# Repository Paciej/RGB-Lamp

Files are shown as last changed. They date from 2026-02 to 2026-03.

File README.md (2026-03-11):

# Smart RGB LED Lamp — BLE Controlled (ESP32)

A Bluetooth Low Energy (BLE) controlled RGB LED lamp built on the ESP32 microcontroller.
The lamp supports multiple lighting modes, real-time color and brightness control,
and temperature monitoring — all controllable wirelessly via **nRF Connect** app.
A dedicated mobile application is currently under development.

---

## PCB Design (Eagle)

> Schematic and board layout designed in Eagle CAD.
<p align="center">
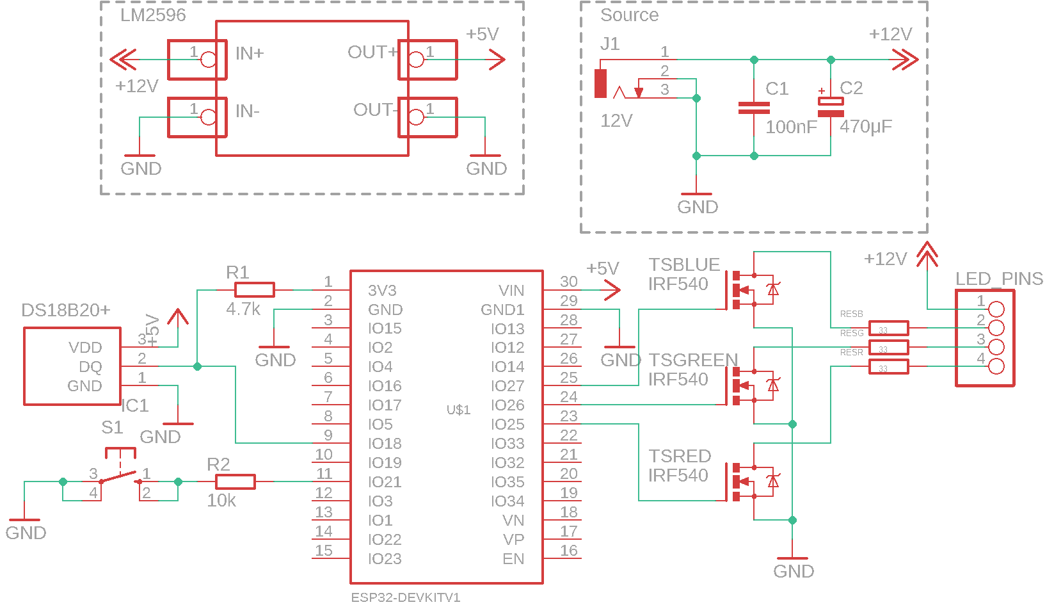
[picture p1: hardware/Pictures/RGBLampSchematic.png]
Eagle Schematic

</p>
<p align="center">
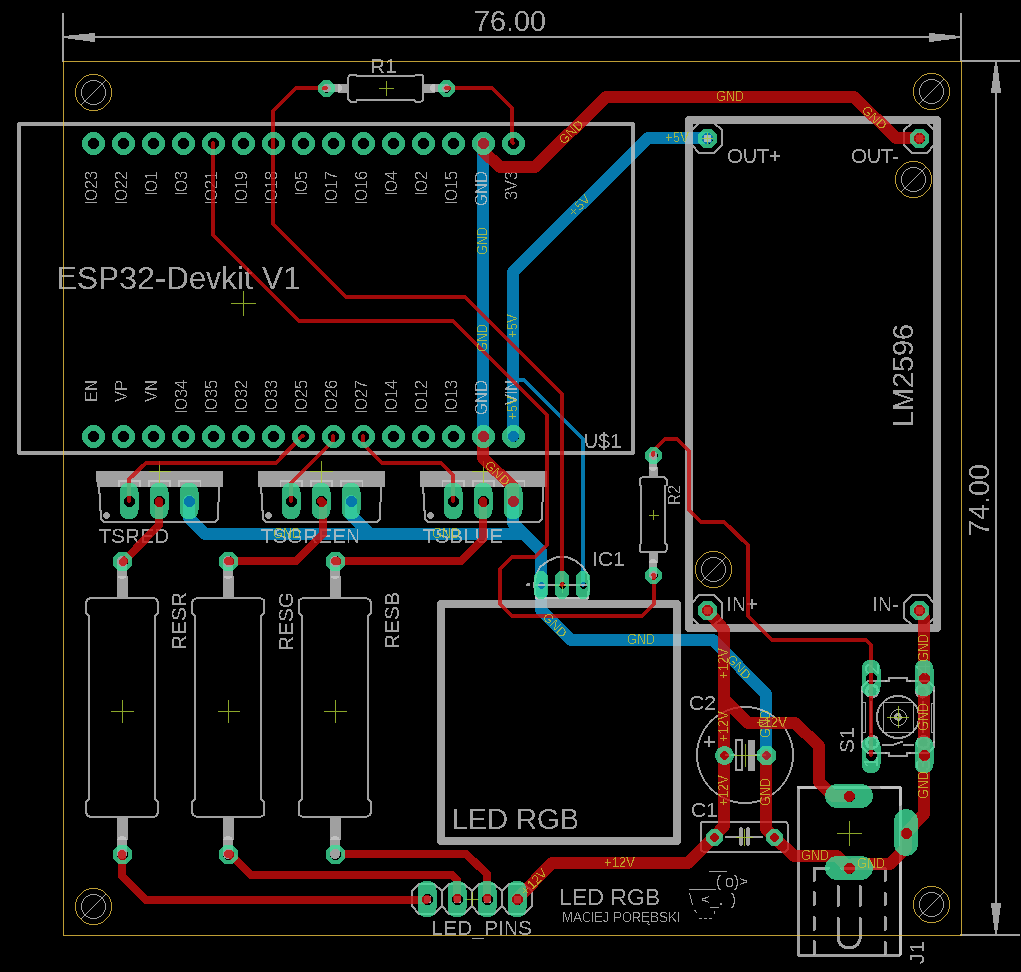
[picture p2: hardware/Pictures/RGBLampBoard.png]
Eagle PCB Layout

</p>
---

## Printed & Assembled PCB

> Physical PCB after printing and soldering.
<p align="center">
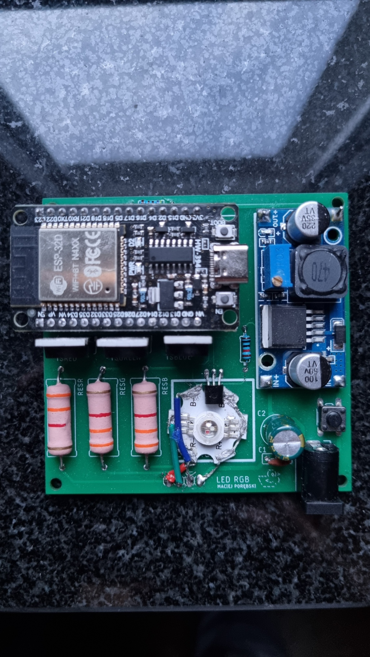
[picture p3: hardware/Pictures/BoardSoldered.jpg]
Soldered PCB
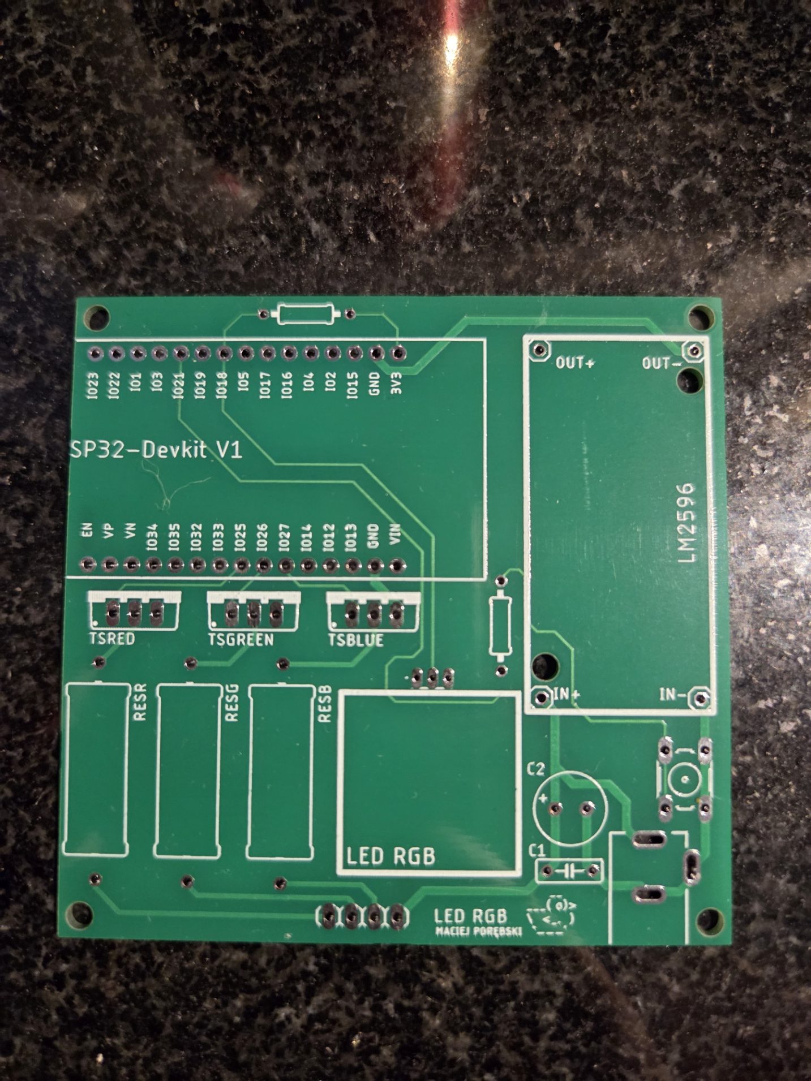
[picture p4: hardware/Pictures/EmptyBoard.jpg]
Printed PCB
 
</p>
---

## Control via nRF Connect

> The lamp is currently controlled using the **nRF Connect** mobile app.
> Temperature readings are exposed as a BLE characteristic and visible directly in the app.
<p align="center">
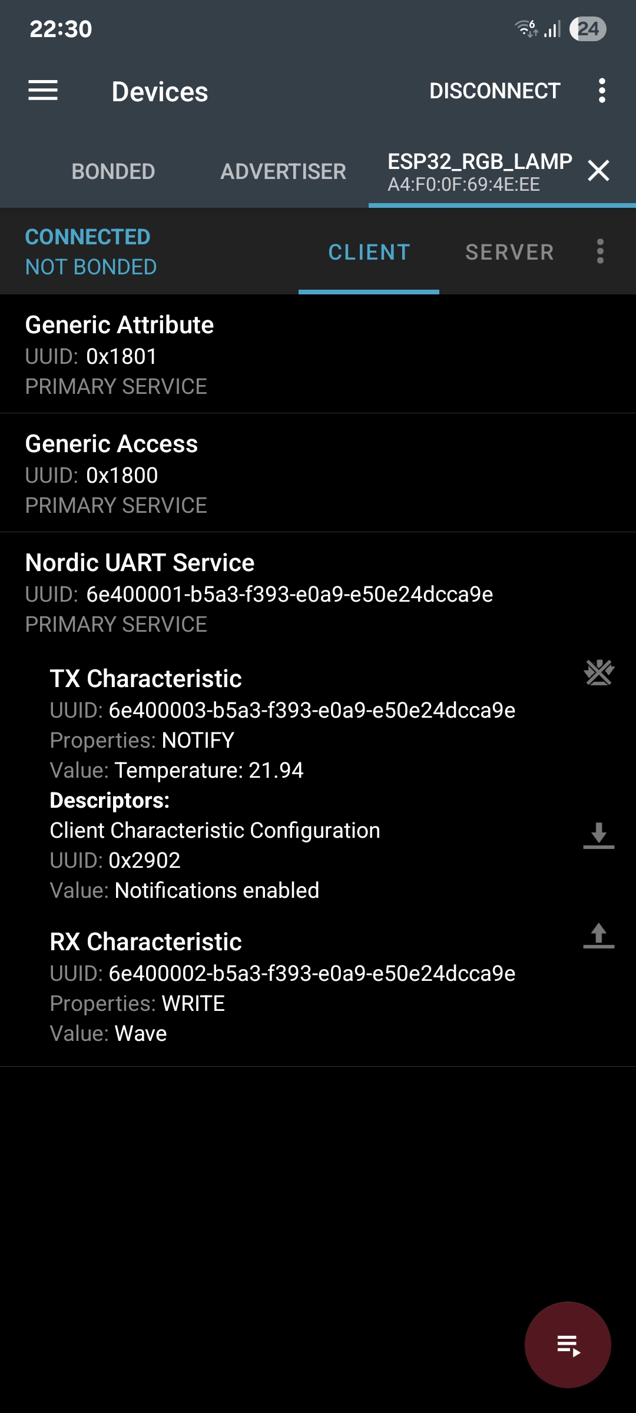
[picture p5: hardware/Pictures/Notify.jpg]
nRF Connect - Temperature Reading

</p>
---

##  Lighting Modes

### Random Color — Physical Button
> Press the physical button to apply a random color using ESP32's hardware RNG.

<p align="center">
  Random Color Button Demo
</p>

---

### Candle Mode
> Simulates a realistic flickering candle effect.

<p align="center">
  Candle Mode Demo
</p>

---

### Pulse Mode
> Smooth brightness breathing effect.

<p align="center">
  Pulse Mode Demo
</p>

---

### Wave Mode
> Seamless smooth transitions across the full RGB spectrum.

<p align="center">
  Wave Mode Demo
</p>

---

##  Features

-  **Full RGB color control** — set any color via BLE (values 0–255 per channel)
-  **Brightness control** via MOSFET PWM (low-side configuration)
-  **Temperature monitoring** — DS18B20 sensor exposed as a BLE characteristic
-  **Random color button** — applies a random color using ESP32's hardware RNG
-  **Lighting modes:**
  - Candle (flicker simulation)
  - Pulse (breathing effect)
  - Wave (smooth RGB transitions)
-  **BLE communication** — controlled via nRF Connect (dedicated app in development)

---

##  Pin Configuration (ESP32 DevKit)

| Pin | Function | Component |
|-----|---|---|
| 23 | Red channel (PWM) | RGB LED — Red |
| 24 | Green channel (PWM) | RGB LED — Green |
| 25 | Blue channel (PWM) | RGB LED — Blue |
| 9 | 1-Wire data | DS18B20 Temperature Sensor |
| 11 | Button input | Random color trigger |

---

##  Hardware Components

| Component | Description |
|---|---|
| **ESP32 DevKit** | Main microcontroller with built-in BLE |
| **RGB LED 3W (Star)** | High-brightness point light source |
| **MOSFET (×3)** | Low-side PWM drivers for each RGB channel |
| **LM2596 Buck Converter Module** | Steps down 12V supply to 3.3V for ESP32 |
| **DS18B20** | Digital 1-Wire temperature sensor |
| **Resistor 33Ω 5W** | Custom current-limiting resistor |
| **Push Button** | Physical control for random color |

>  The repository includes pre-built external libraries for ESP32 DevKit, DS18B20,
> and the custom 33Ω 5W resistor component (Eagle library).

---

##  Libraries

The project uses the following external libraries bundled in the repository:

- `ESP32 BLE Arduino` — BLE GATT server implementation
- `DallasTemperature` + `OneWire` — DS18B20 sensor support
- Custom Eagle component library — 33Ω 5W resistor footprint

---

## Setup

1. Open the project in **Arduino IDE** or **PlatformIO**
2. Select board: `ESP32 Dev Module`
3. Install libraries from the `/libraries` folder (or use the bundled ones)
4. Flash the firmware to your ESP32
5. Open **nRF Connect** on your mobile device
6. Scan for the device and connect
7. Use GATT characteristics to:
   - Write RGB values (3 bytes: R, G, B)
   - Write lighting mode
   - Read temperature

---

##  BLE Control (nRF Connect)

Until the dedicated app is released, the lamp can be fully controlled via **nRF Connect**:

- Write `[R, G, B]` bytes to the color characteristic to set color
- Write a mode byte to switch lighting modes:
  - `Candle` — Candle
  - `Pulse` — Pulse
  - `Wave` — Wave
- Read the temperature characteristic to monitor the LED temperature

---

##  Project Info

- **University:** Silesian University of Technology
- **Faculty:** Faculty of Automatic Control, Electronics and Computer Science
- **Subject:** Microprocessor and embedded systems
- **Author:** Maciej Porębski

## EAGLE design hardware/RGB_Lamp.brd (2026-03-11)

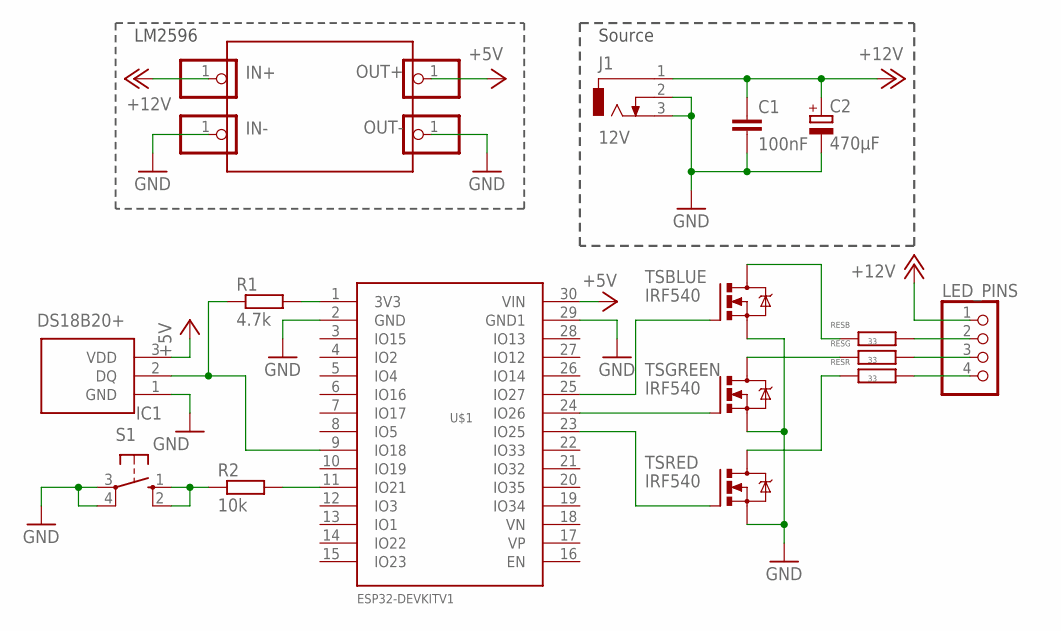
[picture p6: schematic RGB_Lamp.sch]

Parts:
C1: 100nF; C050-025X075
C2: 470μF; E3,5-8
IC1: DS18B20+; DS18B20
IN+: PINHD-1X1; 1X01
IN-: PINHD-1X1; 1X01
J1: 12V; DCJ0303
LED_PINS: PINHD-1X4; 1X04
OUT+: PINHD-1X1; 1X01
OUT-: PINHD-1X1; 1X01
R1: 4.7k; 0207/10
R2: 10k; 0207/10
RESB: 33; 0922/22
RESG: 33; 0922/22
RESR: 33; 0922/22
S1: 10-XX; B3F-10XX
TSBLUE: IRF540; TO220BV
TSGREEN: IRF540; TO220BV
TSRED: IRF540; TO220BV
U$1: ESP32DEVKITV1; ESP32-DEVKITV1

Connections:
+5V: IC1.3 (VDD), OUT+.1, U$1.30 (VIN)
+12V: C1.1, C2.+, IN+.1, J1.1, LED_PINS.1
B: RESR.1, TSRED.D
GND: C1.2, C2.-, IC1.1 (GND), IN-.1, J1.2, J1.3, OUT-.1, S1.3, S1.4 (P1), TSBLUE.S, TSGREEN.S, TSRED.S, U$1.2 (GND), U$1.29 (GND1)
unnamed: R2.1, S1.1 (S), S1.2 (S1)
unnamed: IC1.2 (DQ), R1.1, U$1.9 (IO18)
unnamed: RESG.1, TSGREEN.D
unnamed: R2.2, U$1.11 (IO21)
unnamed: LED_PINS.2, RESB.2
unnamed: LED_PINS.3, RESG.2
unnamed: LED_PINS.4, RESR.2
unnamed: TSRED.G, U$1.23 (IO25)
unnamed: TSGREEN.G, U$1.24 (IO26)
unnamed: TSBLUE.G, U$1.25 (IO27)
unnamed: R1.2, U$1.1 (3V3)
R: RESB.1, TSBLUE.D

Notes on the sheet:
LM2596
Source

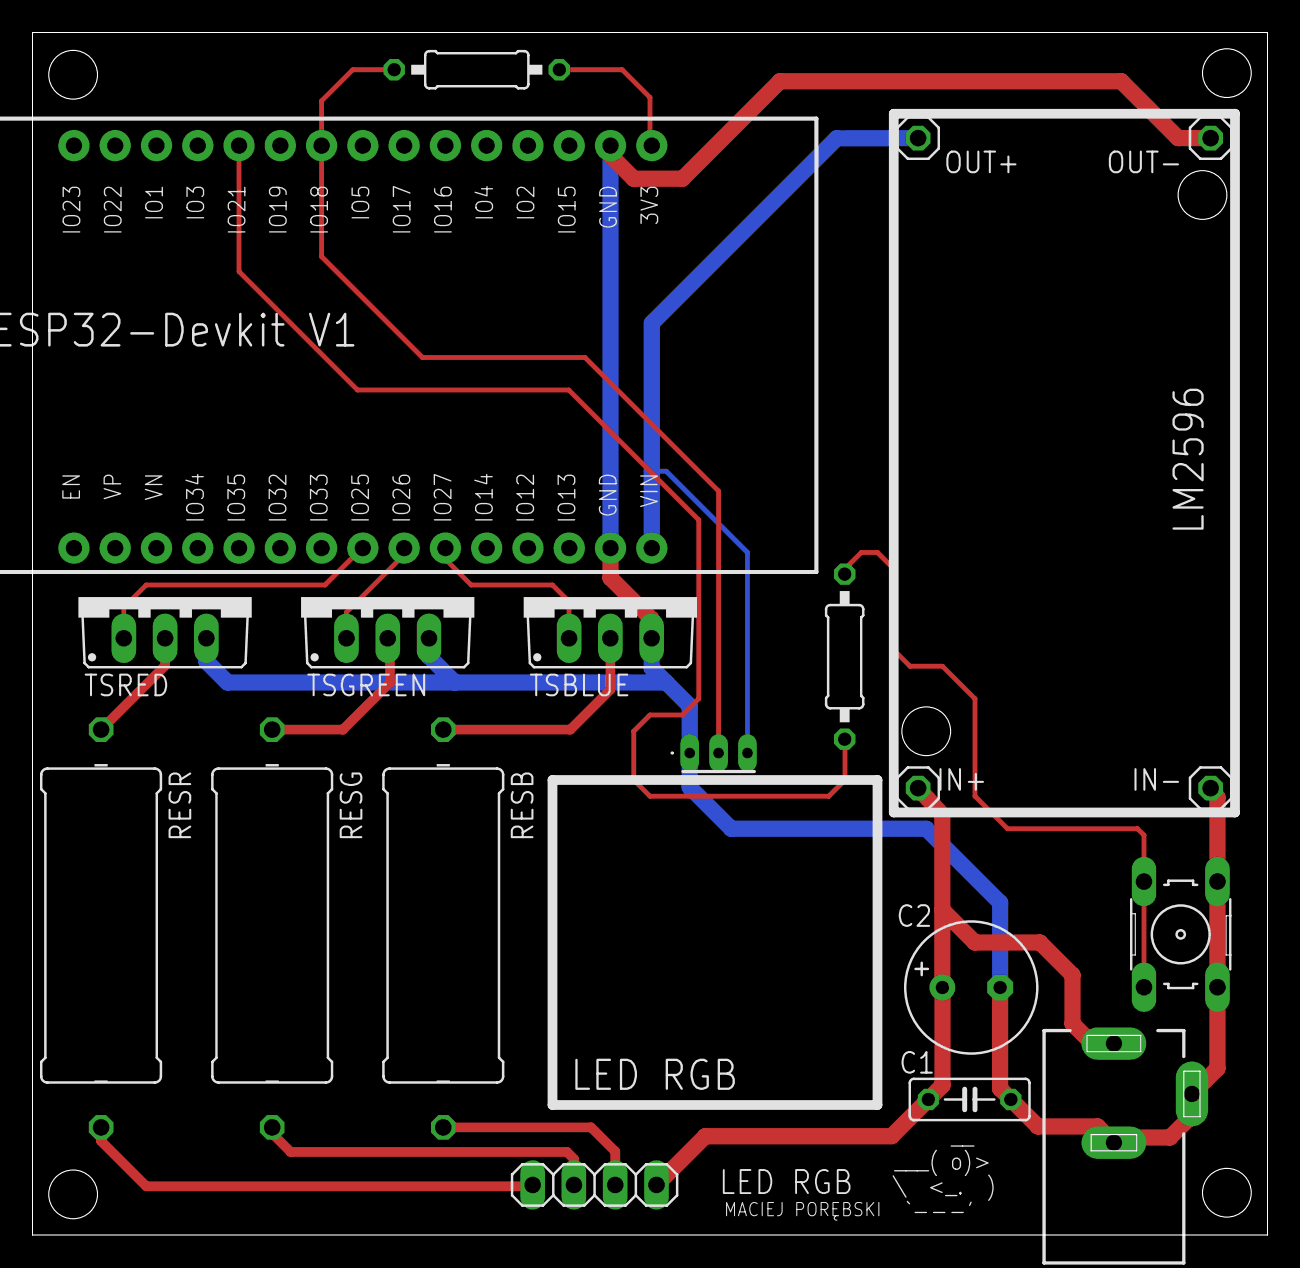
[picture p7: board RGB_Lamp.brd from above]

Board: 2 copper layers, 76.0 x 74.0 mm, 19 parts (0 on the bottom side), 16 nets.

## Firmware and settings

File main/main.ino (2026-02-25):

#include <OneWire.h>
#include <DallasTemperature.h>
#include <esp_random.h>
#include "LedBLEService.h"

/********* Const variables *********/
  // Pins
const unsigned int PIN_RED = 25;
const unsigned int PIN_GREEN = 26; 
const unsigned int PIN_BLUE = 27;
const unsigned int PIN_BUTTON = 21;
const unsigned int PIN_TEMP = 18;

  // Other
const unsigned int LED_CRIT_MAX_INTENSITY = 100;
const unsigned long TEMP_MEASURE_INTERVAL = 5000;
const unsigned long TEMP_CONVERSION_DELAY = 750;
const unsigned long BTN_DEBOUNCE_DELAY = 50;

/****** Variables *******/
enum class ColorModes {
  None,
  Wave,
  Pulse,
  Candle
};
ColorModes currentMode = ColorModes::None;

// RGB LEDs [0..255]
int ledRed = 0;
int ledGreen = 0;
int ledBlue = 0;

// BLE server and connection
LedBLEService ble;

// state variables
bool isLedTempCrit = false;
bool tempRequestPending = false;
unsigned long lastTempRequest = 0;
unsigned long lastTempCheckTime = 0;

// Temperature variables
float lastWrittenTemp = 0;

// button variables
int lastButtonState = HIGH;
unsigned long lastDebounceTime = 0;

// mode variables 
  // wave
float waveSpeed = 60.0;    
  // pulse   
float pulseSpeed = 3.0;   
int baseRed = 0, baseGreen = 0, baseBlue = 0; // for pulse mode remember state
  // candle
unsigned long lastFlicker = 0;
int flickerInterval = 100;
int targetBrightness = 255;
int currentBrightness = 255;

OneWire oneWire(PIN_TEMP);
DallasTemperature tempSensors(&oneWire);

/********** LOGIC **********/

void writeLedStatus() {
    if (!ble.isConnected()) return;
    String response = "RGB: " + String(ledRed) + "," + String(ledGreen) + "," + String(ledBlue);
    ble.sendData(response);
    Serial.printf("RGB values: R=%d G=%d B=%d \n", ledRed, ledGreen, ledBlue);
}


// handle getting color from callback
void handleColorFromBle(int r, int g, int b) {
    ledRed = r;
    ledGreen = g;
    ledBlue = b;
    currentMode = ColorModes::None;
    updateLED();
}

// handle getting mode from callback
void handleModeFromBle(String mode) {
    if (mode == "Wave") {
        currentMode = ColorModes::Wave;
    } else if (mode == "Pulse") {
        currentMode = ColorModes::Pulse;
        baseRed = ledRed;
        baseGreen = ledGreen;
        baseBlue = ledBlue;
    } else if (mode == "Candle") {
        currentMode = ColorModes::Candle;
    }
}

#pragma region led modes
void waveMode() {
  float angle = fmod((millis() * waveSpeed) / 1000.0, 360.0);
  
  ledRed = (sin(angle * PI / 180.0) + 1.0) * 127.5;
  ledGreen = (sin((angle + 120) * PI / 180.0) + 1.0) * 127.5;
  ledBlue = (sin((angle + 240) * PI / 180.0) + 1.0) * 127.5;
  updateLED();
}

void pulseMode() {
  float angle = (millis() * pulseSpeed) / 1000.0;
  float brightnessFactor = (sin(angle) + 1.0) / 2.0; 
  
  // Stosujemy współczynnik jasności do koloru BAZOWEGO
  ledRed = baseRed * brightnessFactor;
  ledGreen = baseGreen * brightnessFactor;
  ledBlue = baseBlue * brightnessFactor;

  updateLED();
}

void candleMode() {
  if (millis() - lastFlicker > flickerInterval) {
    lastFlicker = millis();
    targetBrightness = random(120, 256);
    flickerInterval = random(50, 150); 
  }

  if (currentBrightness < targetBrightness) currentBrightness += 5;
  if (currentBrightness > targetBrightness) currentBrightness -= 5;
  currentBrightness = constrain(currentBrightness, 0, 255);
  int greenFlicker = random(-20, 20);

  ledRed   = currentBrightness;
  ledGreen = constrain(((currentBrightness * 140) / 255) + greenFlicker, 0, 255);
  ledBlue  = (currentBrightness * 10) / 255; 
  updateLED();
}
#pragma endregion

void handleModes() {

  if (currentMode == ColorModes::None) return;

  if (isLedTempCrit) {
    currentMode = ColorModes::None;
    Serial.println("Tryb specjalny zatrzymany przez temperaturę!");
    // Warning color
    ledRed = LED_CRIT_MAX_INTENSITY;
    ledGreen = 0;
    ledBlue = 0;
    updateLED();
    writeLedStatus();
    return;
  }

  switch (currentMode) {
    case ColorModes::None :
      return;
    case ColorModes::Wave :
      waveMode();
      break;
    case ColorModes::Pulse :
      pulseMode();
      break;
    case ColorModes::Candle :
      candleMode();
      break;
  }
}

// Funkcja aktualizacji LED (zabezpieczona)
void updateLED() {
  if (!isLedTempCrit || 
     (ledRed <= LED_CRIT_MAX_INTENSITY && ledGreen <= LED_CRIT_MAX_INTENSITY && ledBlue <= LED_CRIT_MAX_INTENSITY)) {
      ledcWrite(PIN_RED, ledRed);
      ledcWrite(PIN_GREEN, ledGreen);
      ledcWrite(PIN_BLUE, ledBlue);
  } else {
      ble.sendData("Zbyt wysoka temperatura!");
  }
}

// Asynchroniczna obsługa temperatury
void updateTemp() {
  unsigned long currentMillis = millis();

  if (!tempRequestPending && (currentMillis - lastTempCheckTime >= TEMP_MEASURE_INTERVAL)) {
    tempSensors.requestTemperatures();
    tempRequestPending = true;
    lastTempRequest = currentMillis;
    lastTempCheckTime = currentMillis;
  }

  if (tempRequestPending && (currentMillis - lastTempRequest >= TEMP_CONVERSION_DELAY)) {
    float tempC = tempSensors.getTempCByIndex(0);
    tempRequestPending = false;

    if (tempC == -127.00) {
      return; 
      Serial.println("ERROR127: temperature scanner does not work properly");
    }

    if (tempC - lastWrittenTemp != 0) {
      String response = "Temperature: " + String(tempC);
      ble.sendData(response);
      printf("temperatura: %.1f \n", tempC);
      lastWrittenTemp = tempC;
    }

    if (tempC > 85.0 && !isLedTempCrit) {
      isLedTempCrit = true;
      currentMode = ColorModes::None;
      
      String response = "ALARM TEMP: " + String(tempC, 1) + "C";
      ble.sendData(response);
      Serial.printf("%s", response);

      ledRed = (ledRed > LED_CRIT_MAX_INTENSITY) ? LED_CRIT_MAX_INTENSITY : ledRed;
      ledGreen = (ledGreen > LED_CRIT_MAX_INTENSITY) ? LED_CRIT_MAX_INTENSITY : ledGreen;
      ledBlue = (ledBlue > LED_CRIT_MAX_INTENSITY) ? LED_CRIT_MAX_INTENSITY : ledBlue;
      
      updateLED();
    } else if (isLedTempCrit && tempC < 70.0) {
      isLedTempCrit = false;
    }
  }
}

// Obsługa przycisku
void updateButton() {
  int reading = digitalRead(PIN_BUTTON);

  if (reading != lastButtonState) {
    lastDebounceTime = millis();
  }

  if ((millis() - lastDebounceTime) > BTN_DEBOUNCE_DELAY) {
    static int stableState = HIGH;
    if (reading != stableState) {
      stableState = reading;
      if (stableState == LOW) {
        
        currentMode = ColorModes::None;
        
        ledRed = constrain(esp_random() % 256, 0, 255);
        ledGreen = constrain(esp_random() % 256, 0, 255);
        ledBlue = constrain(esp_random() % 256, 0, 255);
        
        if (isLedTempCrit) {
            if(ledRed > LED_CRIT_MAX_INTENSITY) ledRed = LED_CRIT_MAX_INTENSITY;
            if(ledGreen > LED_CRIT_MAX_INTENSITY) ledGreen = LED_CRIT_MAX_INTENSITY;
            if(ledBlue > LED_CRIT_MAX_INTENSITY) ledBlue = LED_CRIT_MAX_INTENSITY;
        }

        updateLED();
        writeLedStatus();
      }
    }
  }
  lastButtonState = reading;
}

void setup() {
  Serial.begin(115200);
  
  ledcAttach(PIN_RED, 5000, 8);
  ledcAttach(PIN_GREEN, 5000, 8);
  ledcAttach(PIN_BLUE, 5000, 8);
  
  pinMode(PIN_BUTTON, INPUT_PULLUP);
  
  tempSensors.begin();
  tempSensors.setWaitForConversion(false);

  ledRed = 100; ledGreen = 100; ledBlue = 100;
  updateLED();

  ble.onColorChange(handleColorFromBle);
  ble.onModeChange(handleModeFromBle);
  ble.init("ESP32_RGB_LAMP");
}

void loop() {

  ble.update();
  updateTemp();    
  updateButton(); 
  handleModes(); 

  delay(10);
}

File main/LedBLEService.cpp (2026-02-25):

#include "LedBLEService.h"

// --- Callback definitions ---

class LedBLEServerCallbacks: public BLEServerCallbacks {
    LedBLEService* ledService;
public:
    LedBLEServerCallbacks(LedBLEService* ls) : ledService(ls) {}
    
    void onConnect(BLEServer* pServer) {
        ledService->isDeviceConnected = true;
        Serial.println("BLE: Device connected");
    };

    void onDisconnect(BLEServer* pServer) {
        ledService->isDeviceConnected = false;
        Serial.println("BLE: Device disconnected");
    }
};

class LedBLECharacteristicCallbacks: public BLECharacteristicCallbacks {
    LedBLEService* ledService;
public:
    LedBLECharacteristicCallbacks(LedBLEService* ls) : ledService(ls) {}

    void onWrite(BLECharacteristic *pCharacteristic) {
        String rxValue = pCharacteristic->getValue();
        
        if (rxValue.length() > 0) {
            String receivedData = String(rxValue.c_str());
            receivedData.trim();
            Serial.printf("BLE Received: %s\n", receivedData.c_str());

            // Logika parsowania (przeniesiona z main)
            if (receivedData == "Wave" || receivedData == "Pulse" || receivedData == "Candle") {
                if (ledService->modeCallback) {
                    ledService->modeCallback(receivedData);
                }
            } else {
                // Próba parsowania koloru R,G,B lub R.G.B
                int firstComma = receivedData.indexOf(',');
                int secondComma = receivedData.indexOf(',', firstComma + 1);
                
                if (firstComma > 0 && secondComma > firstComma) {
                    String redStr = receivedData.substring(0, firstComma);
                    String greenStr = receivedData.substring(firstComma + 1, secondComma);
                    String blueStr = receivedData.substring(secondComma + 1);
                    
                    int r = constrain(redStr.toInt(), 0, 255);
                    int g = constrain(greenStr.toInt(), 0, 255);
                    int b = constrain(blueStr.toInt(), 0, 255);

                    if (ledService->colorCallback) {
                        ledService->colorCallback(r, g, b);
                    }
                }
            }
        }
    }
};

// ----- LedBLEService -----

void LedBLEService::init(String deviceName) {
  BLEDevice::init(deviceName.c_str());
  pServer = BLEDevice::createServer();
  pServer->setCallbacks(new LedBLEServerCallbacks(this));

  BLEService *pService = pServer->createService(SERVICE_UUID);

  pTxCharacteristic = pService->createCharacteristic(
                          CHARACTERISTIC_UUID_TX,
                          BLECharacteristic::PROPERTY_NOTIFY
                      );
  pTxCharacteristic->addDescriptor(new BLE2902());

  BLECharacteristic *pRxCharacteristic = pService->createCharacteristic(
                                            CHARACTERISTIC_UUID_RX,
                                            BLECharacteristic::PROPERTY_WRITE
                                        );
  pRxCharacteristic->setCallbacks(new LedBLECharacteristicCallbacks(this));

  pService->start();

  BLEAdvertising *pAdvertising = BLEDevice::getAdvertising();
  pAdvertising->addServiceUUID(SERVICE_UUID);
  pAdvertising->setScanResponse(false);
  pAdvertising->setMinPreferred(0x0);
  BLEDevice::startAdvertising();
  Serial.println("BLE: Ready and advertising");
}

void LedBLEService::update() {
  if (!isDeviceConnected && isOldDeviceConnected) {
    delay(500); 
    pServer->startAdvertising(); 
    Serial.println("BLE: Restart advertising");
    isOldDeviceConnected = isDeviceConnected;
  }
  if (isDeviceConnected && !isOldDeviceConnected) {
    isOldDeviceConnected = isDeviceConnected;
  }
}

void LedBLEService::sendData(String message) {
  if (isDeviceConnected && pTxCharacteristic) {
    pTxCharacteristic->setValue(message.c_str());
    pTxCharacteristic->notify();
  }
}

bool LedBLEService::isConnected() {
  return isDeviceConnected;
}

void LedBLEService::onColorChange(ColorChangeCallback callback) {
    this->colorCallback = callback;
}

void LedBLEService::onModeChange(ModeChangeCallback callback) {
    this->modeCallback = callback;
}

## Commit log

2026-03-11 Add schematic and board files
    [RGB_Lamp.brd, RGB_Lamp.sch]
2026-03-11 Add README for Smart RGB LED Lamp project
    Added detailed project description, features, and setup instructions for the Smart RGB LED Lamp.
